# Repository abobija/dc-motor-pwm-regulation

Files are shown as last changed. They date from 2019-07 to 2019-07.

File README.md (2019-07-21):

# dc-motor-pwm-regulation
DC Motor PWM speed regulation and IR tachometer

## Description

One MCU is responsible for regulation speed of DC motor with Pulse Width Modulation (PWM), while other MCU have responsibility for measuring that speed. Everything will be easy if there is wire connection between this two MCUs, but there are no physical connection between them. CD which contains four drilled holes, rotates between IR emitting diode, and phototransistor on opposite side. When the hole drilled on CD comes to the sensor, and IR light pass from diode to transistor, internal MCU interrupt will be triggered. Applications for both MCUs are written in plain C.

## Demo
Tachometer - Optical Infra Red (https://www.youtube.com/watch?v=YdqVJecZhuM)

## Microcontrollers

- PWM Generator - `PIC12F628`
- Tachometer - `PIC16F886`

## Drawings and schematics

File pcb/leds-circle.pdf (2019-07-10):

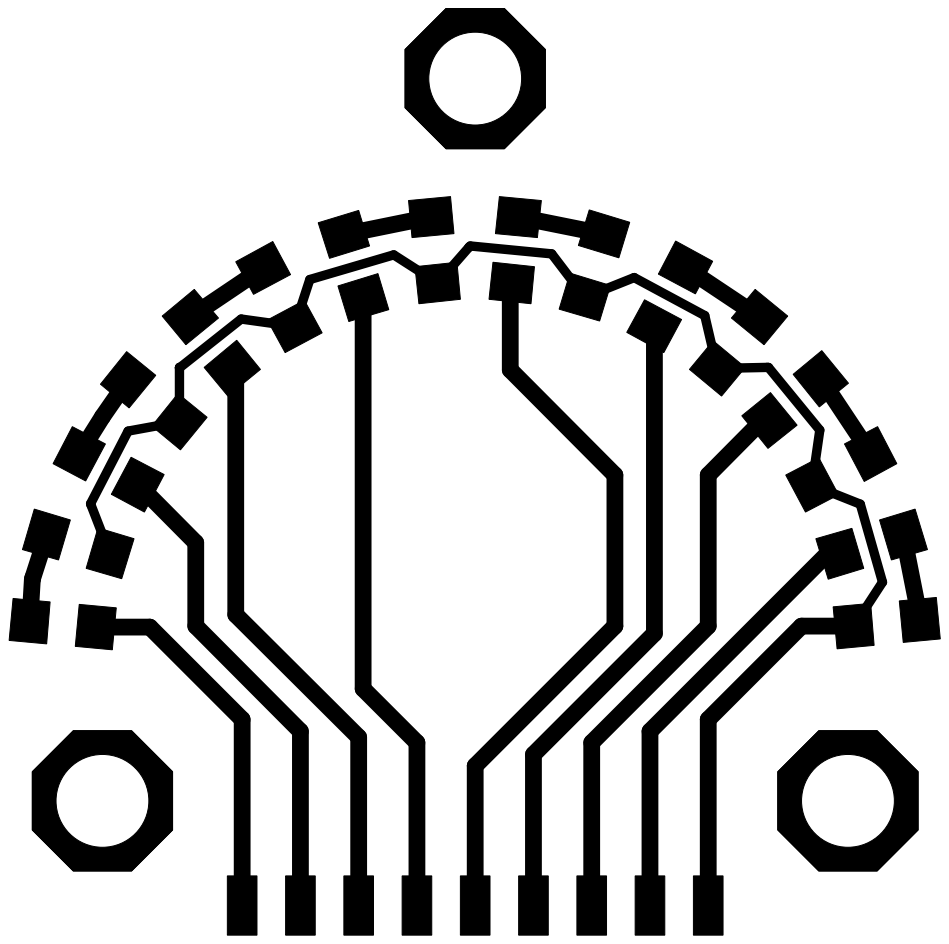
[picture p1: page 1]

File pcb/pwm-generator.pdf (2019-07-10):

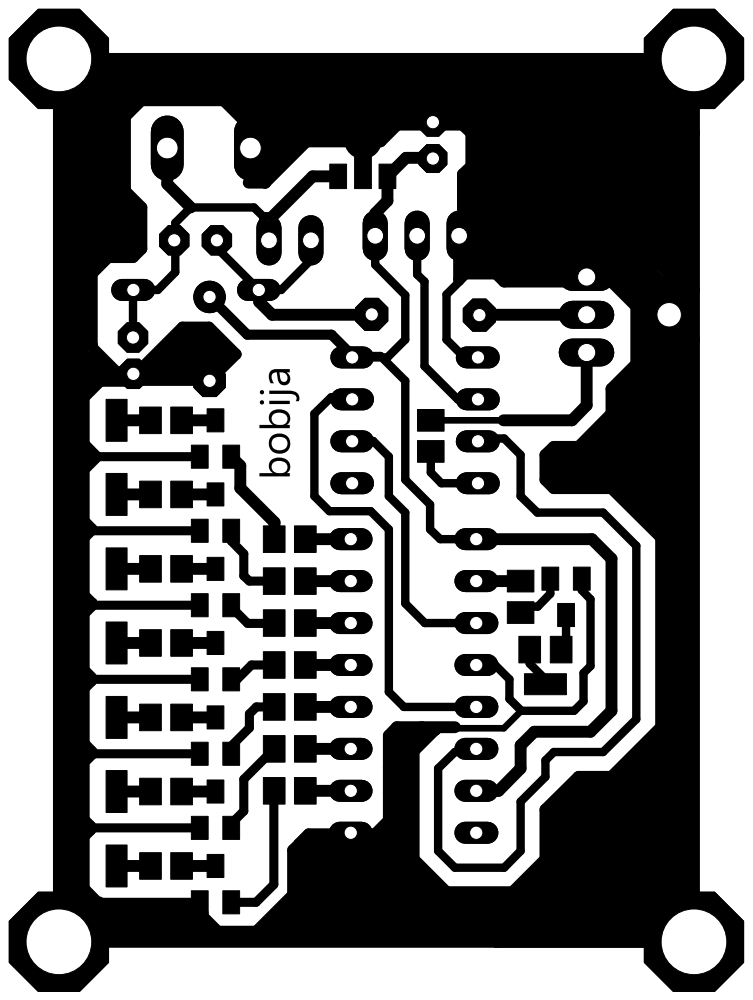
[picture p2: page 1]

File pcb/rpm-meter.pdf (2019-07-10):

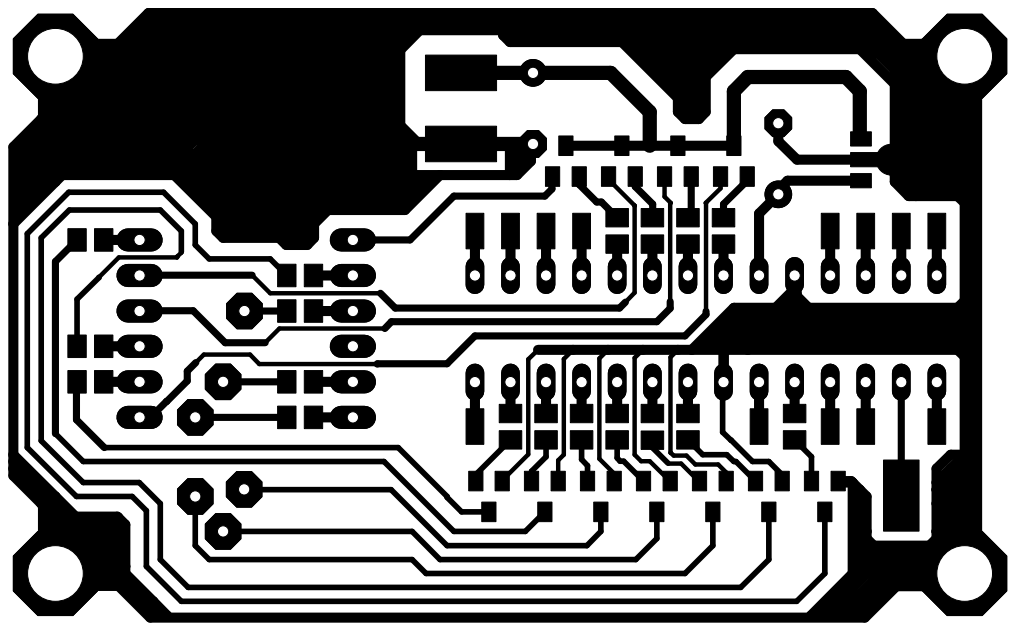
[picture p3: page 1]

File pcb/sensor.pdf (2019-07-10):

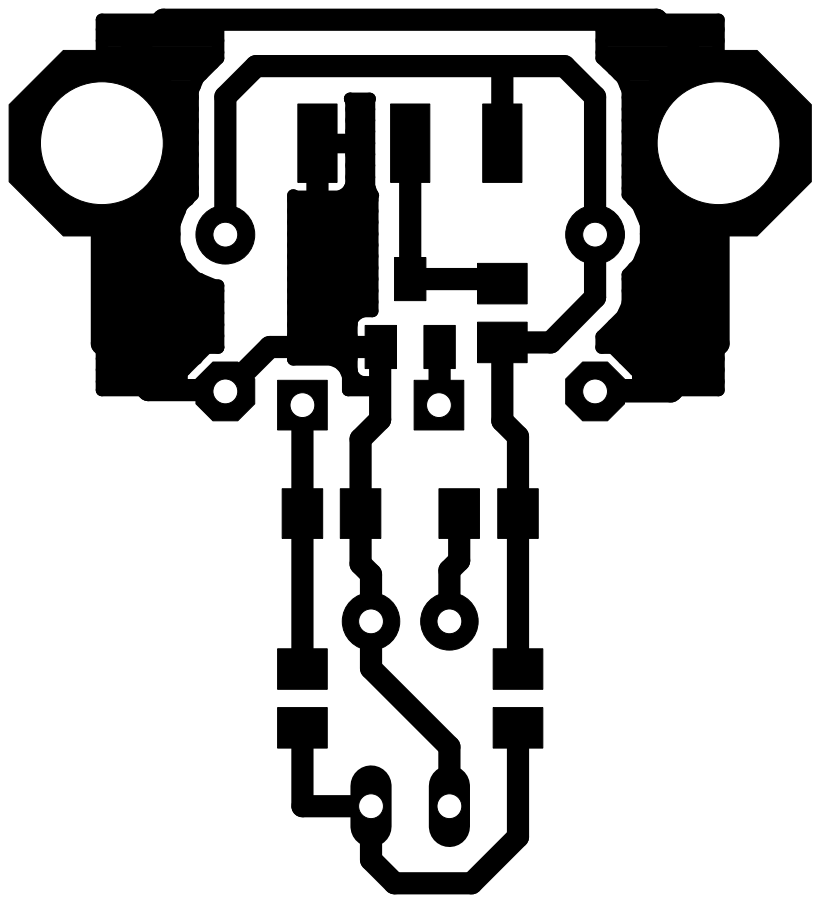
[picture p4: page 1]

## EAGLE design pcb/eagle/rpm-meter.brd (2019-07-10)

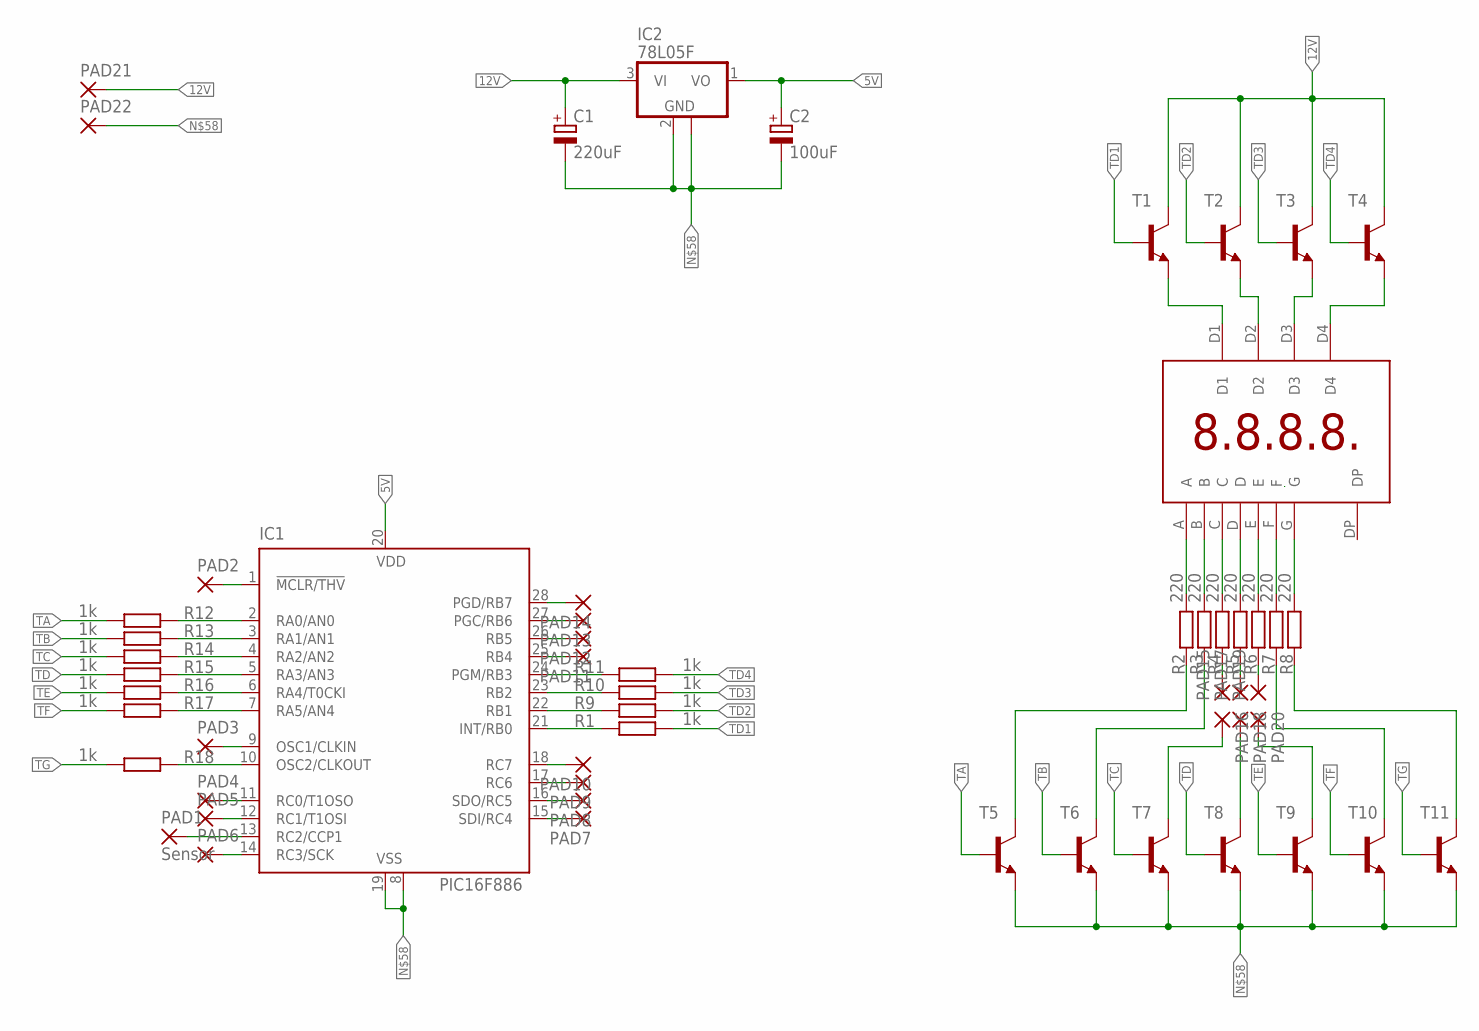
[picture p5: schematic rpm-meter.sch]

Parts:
C1: 220uF; E5-6
C2: 100uF; E5-5
IC1: PIC16F886; DIL28-3
IC2: 78L05F; SOT89
PAD1: Sensor; SMD2,54-5,08
PAD2, PAD3, PAD4, PAD5, PAD6, PAD7, PAD8, PAD9, PAD10, PAD11, PAD12, PAD13, PAD14: SMD2; SMD1,27-2,54
PAD15, PAD16, PAD17, PAD18, PAD19, PAD20: 2,54/0,8
PAD21, PAD22: SMD5; SMD2,54-5,08
R1, R9, R10, R11, R12, R13, R14, R15, R16, R17, R18: 1k; M0805
R2, R3, R4, R5, R6, R7, R8: 220; M0805
T1, T2, T3, T4, T5, T6, T7, T8, T9, T10, T11: -NPN-SOT23-EBC; SOT23-EBC
U$1: 4X7SEG-CA

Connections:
5V: C2.+, IC1.20 (VDD), IC2.1 (VO)
12V: C1.+, IC2.3 (VI), PAD21.1, T1.C, T2.C, T3.C, T4.C
unnamed: R2.2, U$1.A
unnamed: R3.2, U$1.B
unnamed: R4.2, U$1.C
unnamed: R5.2, U$1.D
unnamed: R6.2, U$1.E
unnamed: R7.2, U$1.F
unnamed: R8.2, U$1.G
unnamed: T2.E, U$1.D2
unnamed: T3.E, U$1.D3
unnamed: T1.E, U$1.D1
unnamed: T4.E, U$1.D4
unnamed: PAD17.1, R5.1
unnamed: PAD20.1, T9.C
unnamed: R7.1, T10.C
unnamed: R8.1, T11.C
unnamed: PAD16.1, T7.C
unnamed: R3.1, T6.C
unnamed: R2.1, T5.C
unnamed: IC1.21 (INT/RB0), R1.1
unnamed: IC1.22 (RB1), R9.1
unnamed: IC1.23 (RB2), R10.1
unnamed: IC1.24 (PGM/RB3), R11.1
unnamed: IC1.2 (RA0/AN0), R12.1
unnamed: IC1.3 (RA1/AN1), R13.1
unnamed: IC1.4 (RA2/AN2), R14.1
unnamed: IC1.5 (RA3/AN3), R15.1
unnamed: IC1.6 (RA4/T0CKI), R16.1
unnamed: IC1.7 (RA5/AN4), R17.1
unnamed: IC1.10 (OSC2/CLKOUT), R18.1
unnamed: IC1.13 (RC2/CCP1), PAD1.1
unnamed: IC1.1 (!MCLR/THV), PAD2.1
unnamed: IC1.9 (OSC1/CLKIN), PAD3.1
unnamed: IC1.11 (RC0/T1OSO), PAD4.1
unnamed: IC1.12 (RC1/T1OSI), PAD5.1
unnamed: IC1.14 (RC3/SCK), PAD6.1
unnamed: IC1.15 (SDI/RC4), PAD7.1
unnamed: IC1.16 (SDO/RC5), PAD8.1
unnamed: IC1.17 (RC6), PAD9.1
unnamed: IC1.18 (RC7), PAD10.1
unnamed: IC1.25 (RB4), PAD11.1
unnamed: IC1.26 (RB5), PAD12.1
unnamed: IC1.27 (PGC/RB6), PAD13.1
unnamed: IC1.28 (PGD/RB7), PAD14.1
unnamed: PAD15.1, R4.1
unnamed: PAD19.1, R6.1
unnamed: PAD18.1, T8.C
unnamed: C1.-, C2.-, IC1.8 (VSS), IC1.19 (VSS), IC2.2 (GND), IC2.2@1 (GND), PAD22.1, T5.E, T6.E, T7.E, T8.E, T9.E, T10.E, T11.E
TA: R12.2, T5.B
TB: R13.2, T6.B
TC: R14.2, T7.B
TD: R15.2, T8.B
TD1: R1.2, T1.B
TD2: R9.2, T2.B
TD3: R10.2, T3.B
TD4: R11.2, T4.B
TE: R16.2, T9.B
TF: R17.2, T10.B
TG: R18.2, T11.B

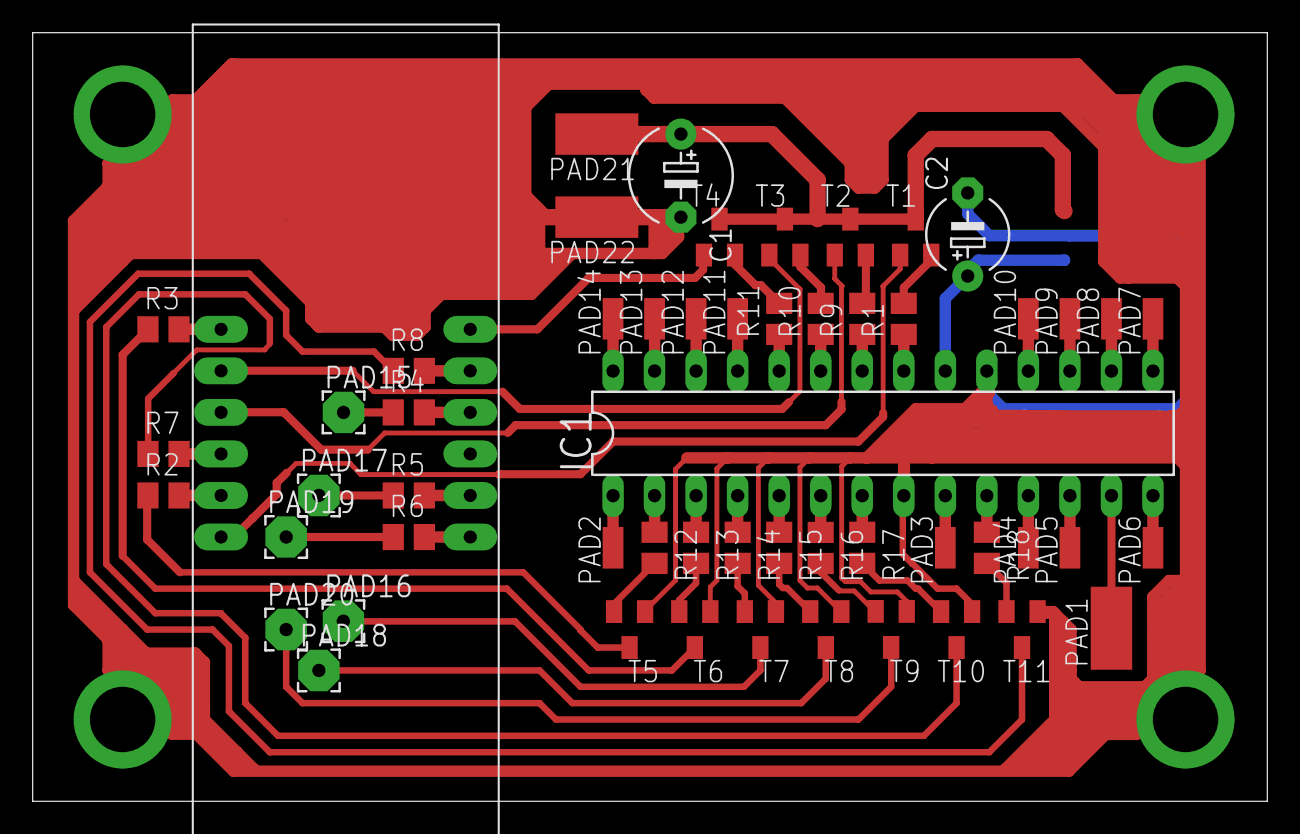
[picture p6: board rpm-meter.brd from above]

Board: 2 copper layers, 75.5 x 47.0 mm, 56 parts (1 on the bottom side), 60 nets.

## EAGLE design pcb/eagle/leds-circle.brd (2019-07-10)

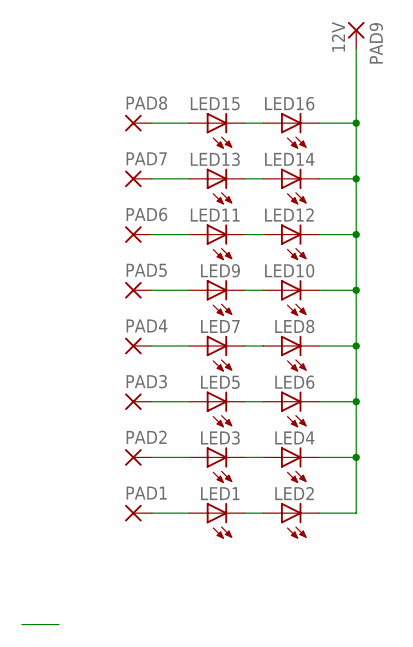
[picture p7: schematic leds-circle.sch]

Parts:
LED1, LED2, LED3, LED4, LED5, LED6, LED7, LED8, LED9, LED10, LED11, LED12, LED13, LED14, LED15, LED16: LED-FKIT-1206; FKIT-LED-1206
PAD1, PAD2, PAD3, PAD4, PAD5, PAD6, PAD7, PAD8: SMD2; SMD1,27-2,54
PAD9: 12V; SMD1,27-2,54

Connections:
unnamed: LED1.C, LED2.A
unnamed: LED3.C, LED4.A
unnamed: LED5.C, LED6.A
unnamed: LED7.C, LED8.A
unnamed: LED9.C, LED10.A
unnamed: LED11.C, LED12.A
unnamed: LED13.C, LED14.A
unnamed: LED15.C, LED16.A
unnamed: LED15.A, PAD8.1
unnamed: LED13.A, PAD7.1
unnamed: LED11.A, PAD6.1
unnamed: LED7.A, PAD4.1
unnamed: LED5.A, PAD3.1
unnamed: LED3.A, PAD2.1
unnamed: LED1.A, PAD1.1
unnamed: LED2.C, LED4.C, LED6.C, LED8.C, LED10.C, LED12.C, LED14.C, LED16.C, PAD9.1
unnamed: LED9.A, PAD5.1

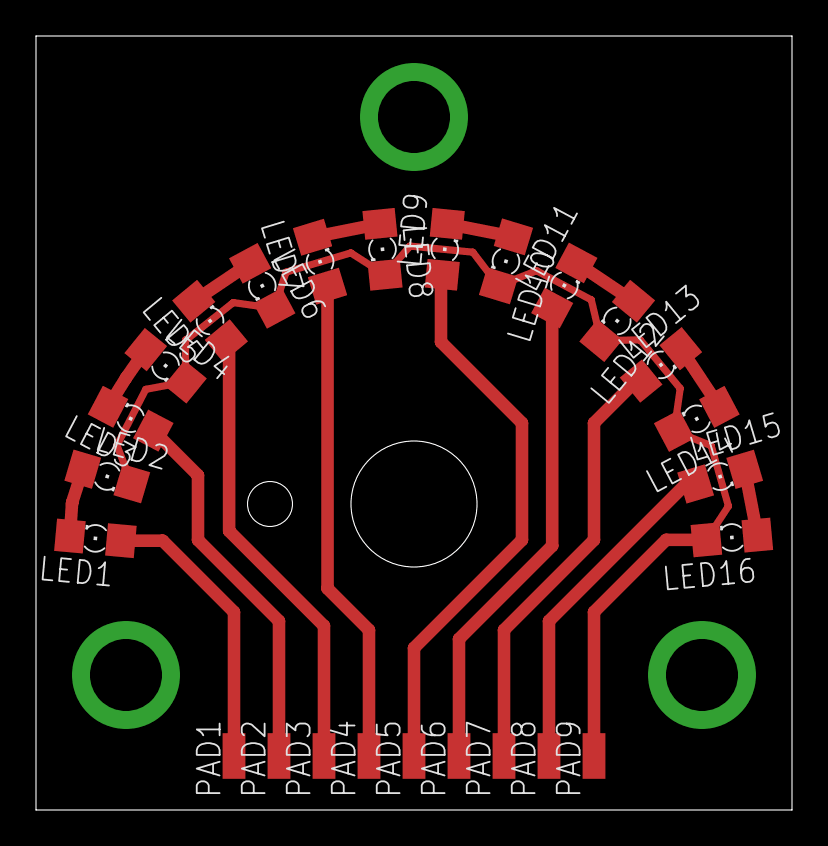
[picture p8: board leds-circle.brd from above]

Board: 2 copper layers, 42.0 x 43.0 mm, 25 parts (0 on the bottom side), 17 nets.

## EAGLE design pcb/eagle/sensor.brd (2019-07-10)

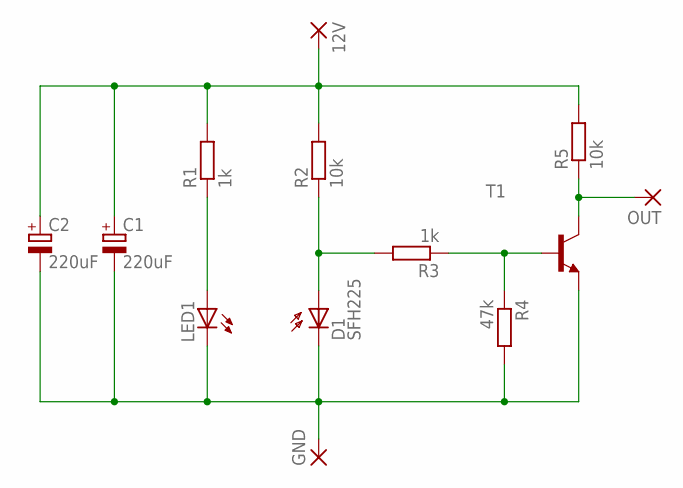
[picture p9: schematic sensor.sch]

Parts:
12V: SMD2; SMD1,27-2,54
C1, C2: 220uF; E5-6
D1: SFH225
GND: SMD2; SMD1,27-2,54
LED1: LED3MM
OUT: SMD2; SMD1,27-2,54
R1, R3: 1k; M0805
R2, R5: 10k; M0805
R4: 47k; M0805
T1: -NPN-SOT23-EBC; SOT23-EBC

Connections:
unnamed: C1.-, C2.-, D1.K (C), GND.1, LED1.K (C), R4.2, T1.E
unnamed: D1.A, R2.1, R3.2
unnamed: LED1.A, R1.1
unnamed: 12V.1, C1.+, C2.+, R1.2, R2.2, R5.2
unnamed: R3.1, R4.1, T1.B
unnamed: OUT.1, R5.1, T1.C

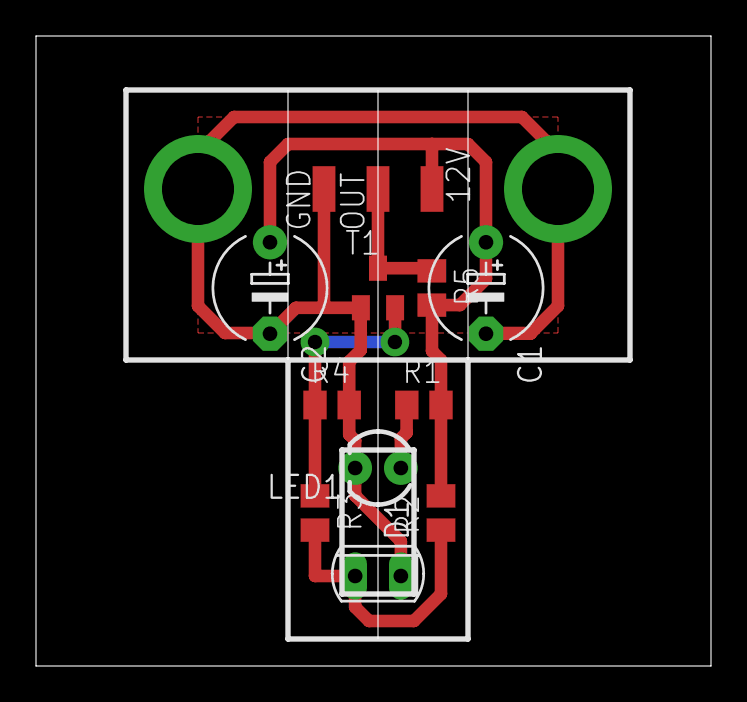
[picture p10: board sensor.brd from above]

Board: 2 copper layers, 37.5 x 35.0 mm, 13 parts (0 on the bottom side), 6 nets.

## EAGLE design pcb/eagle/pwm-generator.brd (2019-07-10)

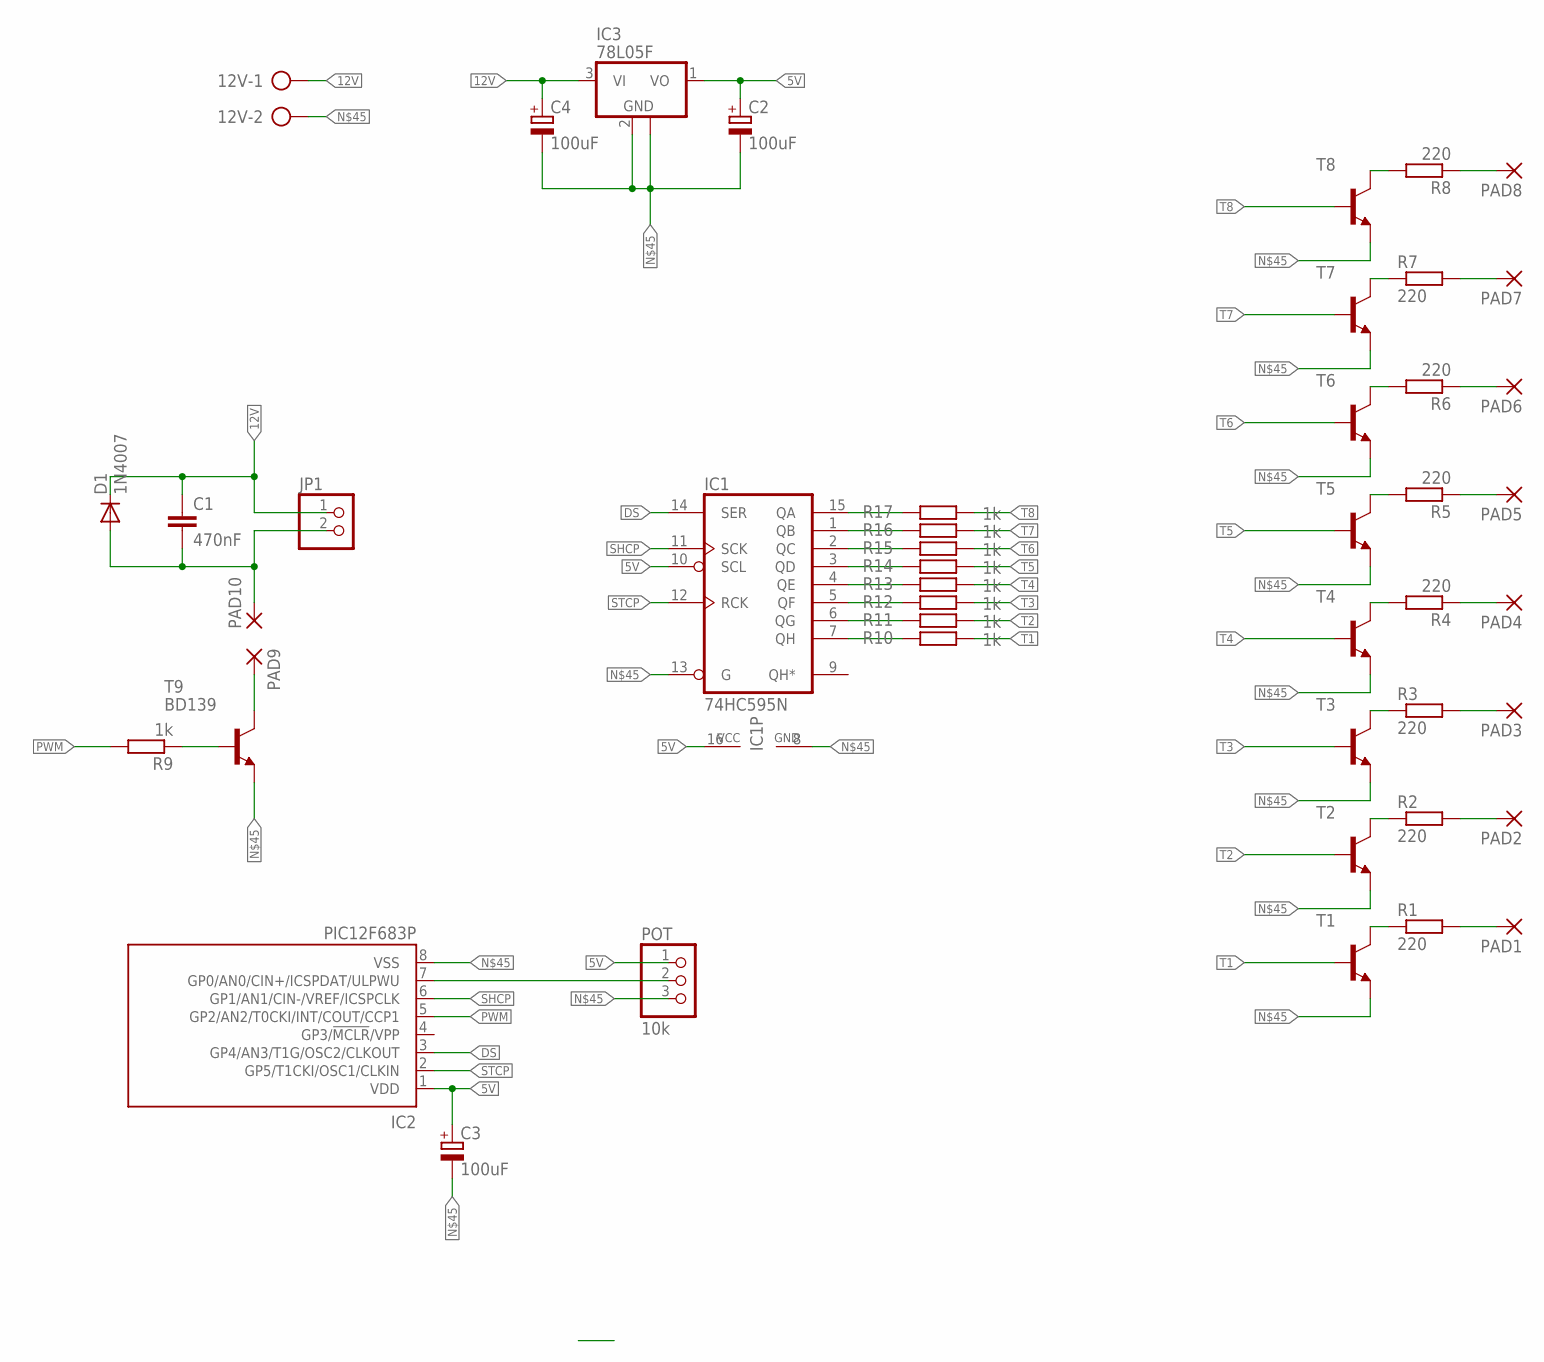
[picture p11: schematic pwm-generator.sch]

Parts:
12V: AK500/2
C1: 470nF; C025-025X050
C2, C4: 100uF; E2-5
C3: 100uF; E5-4
D1: 1N4007; DO35-7
IC1: 74HC595N; DIL16
IC2: PIC12F683P; DIL8
IC3: 78L05F; SOT89
JP1: PINHD-1X2; 1X02
PAD1, PAD2, PAD3, PAD4, PAD5, PAD6, PAD7, PAD8: SMD2; SMD1,27-2,54
PAD9, PAD10: 1,6/0,8
POT: 10k; 1X03
R1, R2, R3, R4, R5, R6, R7, R8: 220; M0805
R9, R10, R11, R12, R13, R14, R15, R16, R17: 1k; M0805
T1, T2, T3, T4, T5, T6, T7, T8: -NPN-SOT23-EBC; SOT23-EBC
T9: BD139; TO126

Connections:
5V: C2.+, C3.+, IC1.10 (SCL), IC1.16 (VCC), IC2.1 (VDD), IC3.1 (VO), POT.1
12V: 12V.1, C1.1, C4.+, D1.C, IC3.3 (VI), JP1.1
DS: IC1.14 (SER), IC2.3 (GP4/AN3/T1G/OSC2/CLKOUT)
unnamed: IC1.7 (QH), R10.2
unnamed: IC1.6 (QG), R11.2
unnamed: IC1.5 (QF), R12.2
unnamed: IC1.4 (QE), R13.2
unnamed: IC1.3 (QD), R14.2
unnamed: IC1.2 (QC), R15.2
unnamed: IC1.1 (QB), R16.2
unnamed: IC1.15 (QA), R17.2
unnamed: IC2.7 (GP0/AN0/CIN+/ICSPDAT/ULPWU), POT.2
unnamed: C1.2, D1.A, JP1.2, PAD10.1
unnamed: R9.1, T9.3 (B)
unnamed: R1.1, T1.C
unnamed: R2.1, T2.C
unnamed: R3.1, T3.C
unnamed: R4.2, T4.C
unnamed: R5.2, T5.C
unnamed: R6.2, T6.C
unnamed: R7.1, T7.C
unnamed: R8.2, T8.C
unnamed: PAD8.1, R8.1
unnamed: PAD7.1, R7.2
unnamed: PAD6.1, R6.1
unnamed: PAD5.1, R5.1
unnamed: PAD4.1, R4.1
unnamed: PAD3.1, R3.2
unnamed: PAD2.1, R2.2
unnamed: PAD1.1, R1.2
unnamed: PAD9.1, T9.2 (C)
unnamed: 12V.2, C2.-, C3.-, C4.-, IC1.8 (GND), IC1.13 (G), IC2.8 (VSS), IC3.2 (GND), IC3.2@1 (GND), POT.3, T1.E, T2.E, T3.E, T4.E, T5.E, T6.E, T7.E, T8.E, T9.1 (E)
PWM: IC2.5 (GP2/AN2/T0CKI/INT/COUT/CCP1), R9.2
SHCP: IC1.11 (SCK), IC2.6 (GP1/AN1/CIN-/VREF/ICSPCLK)
STCP: IC1.12 (RCK), IC2.2 (GP5/T1CKI/OSC1/CLKIN)
T1: R10.1, T1.B
T2: R11.1, T2.B
T3: R12.1, T3.B
T4: R13.1, T4.B
T5: R14.1, T5.B
T6: R15.1, T6.B
T7: R16.1, T7.B
T8: R17.1, T8.B

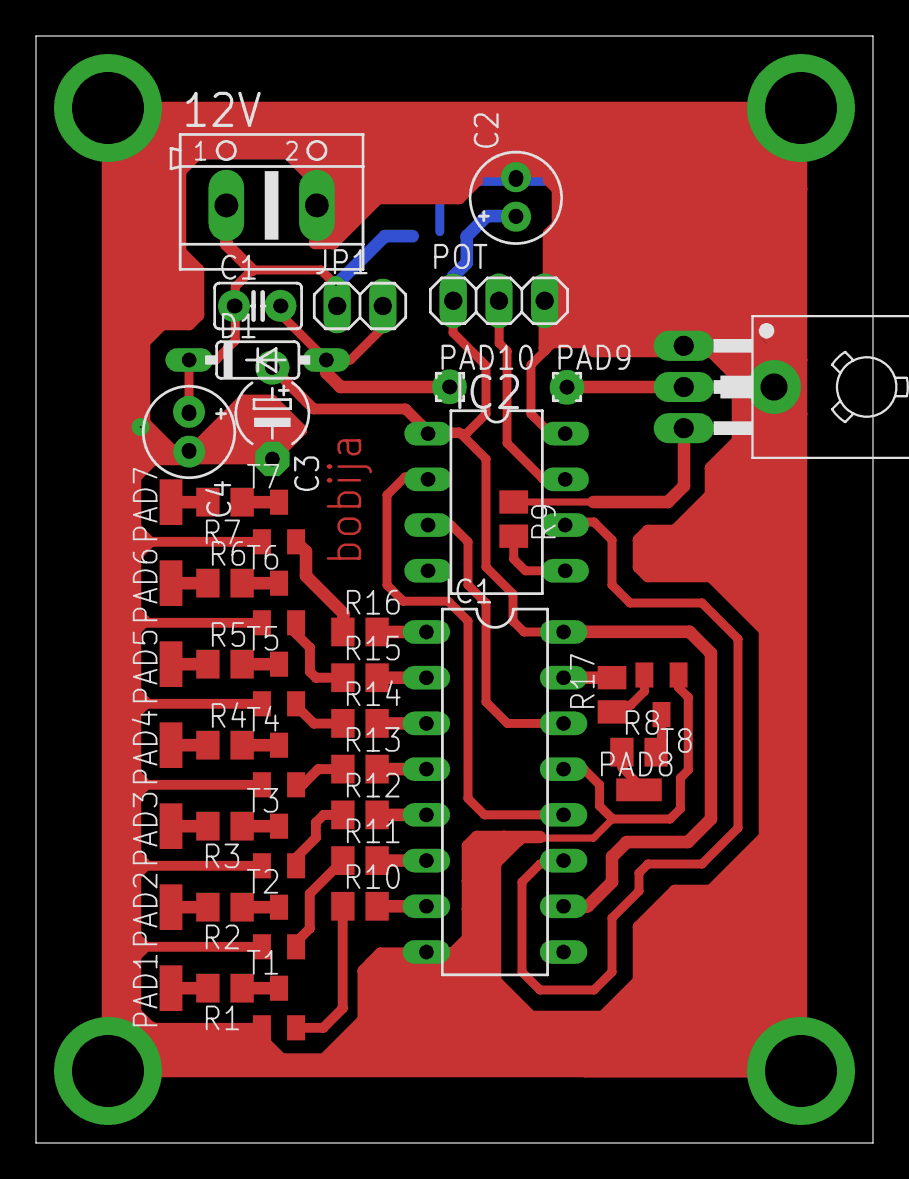
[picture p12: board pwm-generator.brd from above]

Board: 2 copper layers, 46.5 x 61.5 mm, 47 parts (1 on the bottom side), 43 nets.

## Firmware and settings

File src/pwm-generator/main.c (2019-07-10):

unsigned pot;
char duty, leds, i;

void main()
{
  CMCON0 = 0x07;
  ANSEL = 0x01;
  TRISIO = 0x01;
  GPIO = 0x01;
  
  ADC_Init();
  
  PWM1_Init(5000);
  PWM1_Set_Duty(0);
  PWM1_Start();

  while(1)
  {
    pot = ADC_Read(0);
    duty = pot < 32 ? 0 : (pot > 1023-32 ? 255 : pot * (255 / 1023f));
    PWM1_Set_Duty(duty);
   
    leds = duty * (8 / 255f);
    
    GP5_bit = 0;
    for(i = 0; i < 8; i++)
    {
      GP1_bit = 0;
      GP4_bit = leds > i;
      GP1_bit = 1;
    }
    GP5_bit = 1;
  }
}

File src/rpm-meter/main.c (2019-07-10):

unsigned rpmtmp = 0, rpm = 0, rpmabsdiff = 0, ovfcnttmp = 0, ovfcnt = 0;
char map[] = { 0x3F, 0x06, 0x5B, 0x4F, 0x66, 0x6D, 0x7D, 0x07, 0x7F, 0x6F };
char dig[4], i;

void interrupt()
{
  if(CCP1IF_bit)
  {
    ovfcnt = ovfcnttmp;
    ovfcnttmp = 0;
    TMR1L = 0;
    TMR1H = 0;
    TMR1IF_bit = 0;
    CCP1IF_bit = 0;
  }
  
  if(TMR1IF_bit)
  {
    ovfcnttmp++;
    TMR1IF_bit = 0;
  }
}

void main() {
  IRCF0_bit = 1;
  
  ANSEL = 0x00;
  ANSELH = 0x00;
  TRISA = 0x00;
  PORTA = 0x00;
  
  TRISB = 0x00;
  PORTB = 0x00;

  CCP1CON = 0x06; // Capture mode, every 4th rising edge
  
  TRISC2_bit = 1;
  CCP1IF_bit = 0;
  CCP1IE_bit = 1;

  TMR1CS_bit = 0; // The clock source is FOSC/4.
  T1SYNC_bit = 1; // Don't synchronize
  
  T1CKPS1_bit = 0;
  T1CKPS0_bit = 1; // 1:2

  TMR1IE_bit = 1;
  TMR1IF_bit = 0;
  PEIE_bit = 1;
  TMR1ON_bit = 1;
  
  TMR1L = 0;
  TMR1H = 0;
  
  GIE_bit = 1;
  
  while(1)
  {
    rpmtmp = 60e6 / (ovfcnt * (unsigned long)0xFFFF + CCPR1);

    rpmabsdiff = abs(rpmtmp - rpm);

    if(rpmtmp < 7e3 && rpmabsdiff >= 3 && (rpmtmp <= 57e2 || (rpmtmp > 57e2 && rpmabsdiff < 175)))
    {
      rpm = rpmtmp;
    }

    if(ovfcnttmp > 7)
    {
      rpm = 0;
      ovfcnttmp = 8;
    }
    
    dig[0] = rpm / 1000;
    dig[1] = (rpm / 100) % 10;
    dig[2] = (rpm / 10) % 10;
    dig[3] = rpm % 10;

    PORTB = 0x01;

    for(i = 0; i < 4; i++)
    {
      PORTA = map[dig[i]];
      Delay_ms(3);
      PORTA = 0x00;
      PORTB <<= 1;
    }
  }
}

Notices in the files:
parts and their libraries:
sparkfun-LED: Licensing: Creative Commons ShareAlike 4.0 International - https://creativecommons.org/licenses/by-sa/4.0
